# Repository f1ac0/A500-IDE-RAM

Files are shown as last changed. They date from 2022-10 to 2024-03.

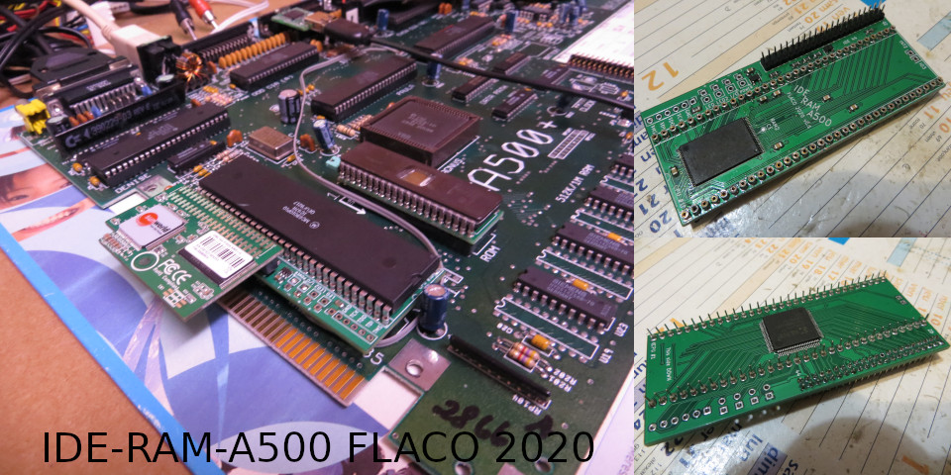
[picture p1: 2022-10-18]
A500-IDE-RAM FLACO 2020.jpg

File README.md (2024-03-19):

# A500-IDE-RAM
This is an expansion for Amiga 500 and plus providing 2MB Fast SRAM and one IDE port. I believe the two things that the A500 lacks the most are probably a hard drive, and Fast RAM.

The RAM is configured by default as 2MB Fast autoconfig (in the 200000-9FFFFF space), and it can be turned into a 1.5MB (fast) RAM in ranger space (C00000-D7FFFF) together with 512KB MapROM. This mode is targeted for owners of plus or expanded rev8a who want to play old picky games from floppies. The modes and maprom can be configured by maintaining the reset from 3 to 10s or by using the provided Amiga software.

Facts about this project :
- It sits under the CPU : does not block access to the ROM and does not need a relocator.
- I wanted a mini-IDE port, this is the main reason why I started to create my own board.
- I thought that it would be neat to have some Fast RAM on the same 2-layers PCB, and I had a great SRAM chip for another project, PCMCIA-SRAM.
- The IDE port simulates the one from the A600 so it is bootable with appropriate Kickstarts. Like other IDE expansions, it requires two additional signals from the motherboard : INT2 and OVR.
- By default, the RAM stuff takes the place of the first expansion in the autoconfig chain. To use other autoconfig expansions, you need to configure the firmware with config_in/out pins to put it in your autoconfig chain ; these pins take the place of the secondary LED.
- Version 0.3 of the board adds a "clockport" to connect compatible expansions. Its "SPARE_CS" is at address D8xxxx. It is untested at the time of writing

# Acknowledgements
Thanks Guys :
- mkl from http://www.mkl211015.altervista.org has created both IDE and RAM expansions, ide68k and ram68k, that sit under the 68000, and can be stacked. I thank him for publishing his schematic and code since it inspired this project, and the base of the IDE CPLD code is a verilog conversion I made from his abel of version 425.
- Sector101 shared an interesting experiment that proved it is somewhat simple to use SRAM as fast memory, and encouraged me to try adding it to this project : https://blog.sector101.co.uk/2019/07/20/amiga-500-2mb-handwired-fastram-expansion/ .
- Sukkopera shared the OpenAmiga500FastRamExpansion from which I used the autoconfig CPLD code in earlier versions : https://github.com/SukkoPera/OpenAmiga500FastRamExpansion/
- the software in this project is inspired by the MapROM tool shared by Paul RASPA (PR77) https://github.com/PR77/A600_ACCEL_RAM/tree/master/Software . This is the first C code I ever compiled for my Amiga, so I believe the MapROM function was achieved thanks to this working starting point !

# Disclaimer
This is a hobbyist project, it comes with no warranty and no support. Also remember that the Amiga machines are about 30 years old and may fail because of such hardware expansions.

I publish my work under the CC-BY-NC-SA license. The content of this repository is the result of weeks of work, requiring investment in tools, parts, prototypes, and risky tests on his own equipment. For this reason the author does not want third parties to sell products and keep all the profit, usually without even offering support to their customers. If you see people selling this without the consent of the author, don't buy from them.

If you find it useful and want to reward my hard work : I am always looking for Amiga/Amstrad CPC hardware to repair and hack, please contact me.

# BOM
- 1x XC95144XL CPLD
- 1x CY62167ELL-45ZXI 5V SRAM (do not use 3.3V CY62167EV !). For 4MB you may also, with small changes in the CPLD code (addressing and autoconfig) :
 - stack a second chip on the first one and connect its pin 12 to the pad nearby -god skills required-,
 - use a CY62177ESL-55ZXI 5V SRAM instead (rare, expensive, not tested).
- 1x 3.3v LDO, either SPX3819M5-L-3-3 or XC6206P332MR
- 2x 1uF (or more) 0805 capacitors
- 5x 100nF 0805 capacitors
- 3x 10k 0805 resistors
- 2x 4k7 0805 resistors
- 1x BAT54A (or equivalent) diodes
- 64x rounded socket pins, for CPU pass-through connection. I use pins taken from a socket header.
- 1x 2x22 2.0mm pin header. Remove pin 20 which is IDE key.
- 2x wires for INT2 and OVR signals
- optional : 1x LED and resistor (330 ohm 0805 for example)

# Making it
Components are SMD, and have thin pin pitch. You need to know what you are doing.

Check for shorts at least between 5V, 3.3V, and GND traces before applying power !

The programming port does not need to be soldered since it needs to be programmed just once : you can just hold it in place during the few seconds required for programming.

CPLD code is generated and built into xsvf using Xilinx ISE 14.7 IDE then iMPACT. There are configuration defines for RAM type and LED/config_pins selection, choose the ones you need. The "Process Properties" of the Fitting step are tweaked :
- -slew = Slow
- -power = Low
- -nogclkopt = Checked (by default)
- -nogsropt = Checked (by default)
- -unused = NOT Checked (by default), since pin 4 is used as pass-through

There are several methods to program the XC95144XL, I personally use xsvfduino. I advise you program it when unplugged from the motherboard, otherwise make sure to power it from the motherboard and not your programmer or it might burn trying to power the whole system.

# Using it
- Remove the 68000 CPU from the motherboard
- Insert the CPU on the expansion. I personally upgraded to a 68010 to gain the quit key ability with WHDLoad
- Plug the expansion in the motherboard. Take care of Pin 1. Push it firmly so it does not pop out of the socket during use, but do not break the CPU socket.
- Connect INT2 and OVR headers to the motherboard
- On the v0.3 board, connect INT6 to use the clockport expansions that need it
- Turn on the Amiga

Maintaining the reset for a few seconds will allow you to :
- 3s : disable MapROM for the next reboot
- 6s : turn off MapROM
- 10s : toggle the ram mode

# Amiga FLACOntrol Software
You may use the provided FLACOntrol software to control the board from your OS. It exists in several flavours, with classic or unix-like command line arguments, or silent with minimal text output.

It provides a MapROM function that writes a 256K or 512K ROM image to F80000-FFFFFF.
It also communicates with this expansion using a control register byte at $00E9Cxxx :
- bit 7 indicates if MapROM is active, write 0 to disable it at next reboot ;
- bit 6 is the current ram mode, 0 for Fast autoconfig and 1 for Ranger MapROM ; write it to change mode at next reboot.

To activate Ranger RAM with MapROM ; this will take effect at next reboot :
```
FLACOntrol -1
```
To map the internal ROM (might speed up the system) :
```
FLACOntrol -i
```
Or a different ROM from file, 256K and 512K are supported :
```
FLACOntrol -f Files:path/kickstart-image-not-swapped-nor-split.rom
```
It will revert to the hardware ROM at next power cycle or with :
```
FLACOntrol -x
```
And revert to the full autoconfig RAM and reboot immediately to take effect :
```
FLACOntrol -0 -r
```

To use the MapROM function more extensively, you may compile the CPLD firmware to provide MapROM by default, then add the following line to your startup-sequence. The -r flag tells the software to reboot the system after the new ROM is loaded, then during next reboot the software will exit since MapROM is already active, and your system will finish to boot with the new ROM :
```
FLACOntrol -f Files:path/kickstart-image-not-swapped-nor-split.rom -r
```

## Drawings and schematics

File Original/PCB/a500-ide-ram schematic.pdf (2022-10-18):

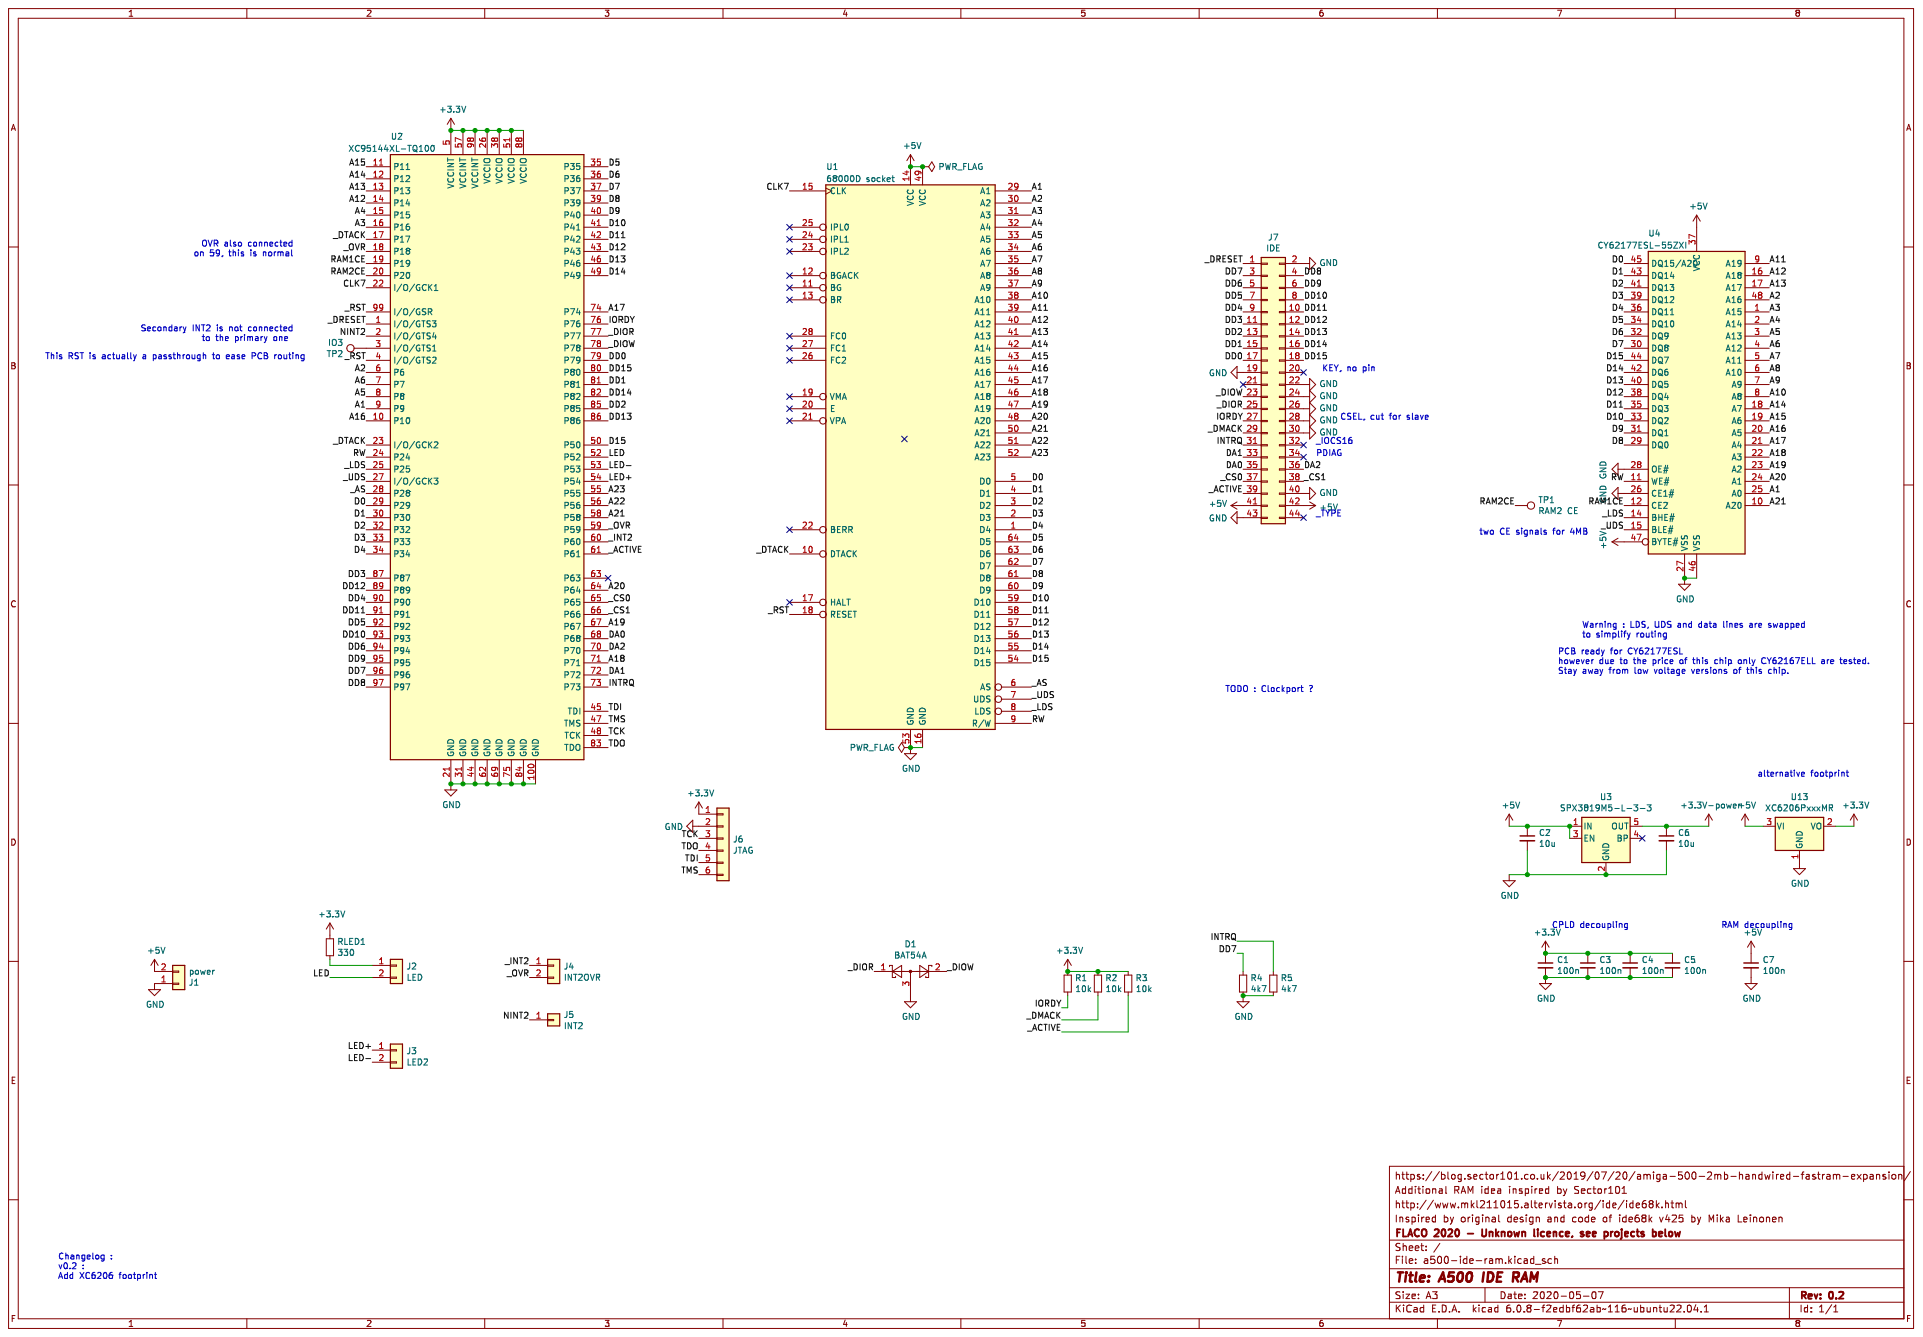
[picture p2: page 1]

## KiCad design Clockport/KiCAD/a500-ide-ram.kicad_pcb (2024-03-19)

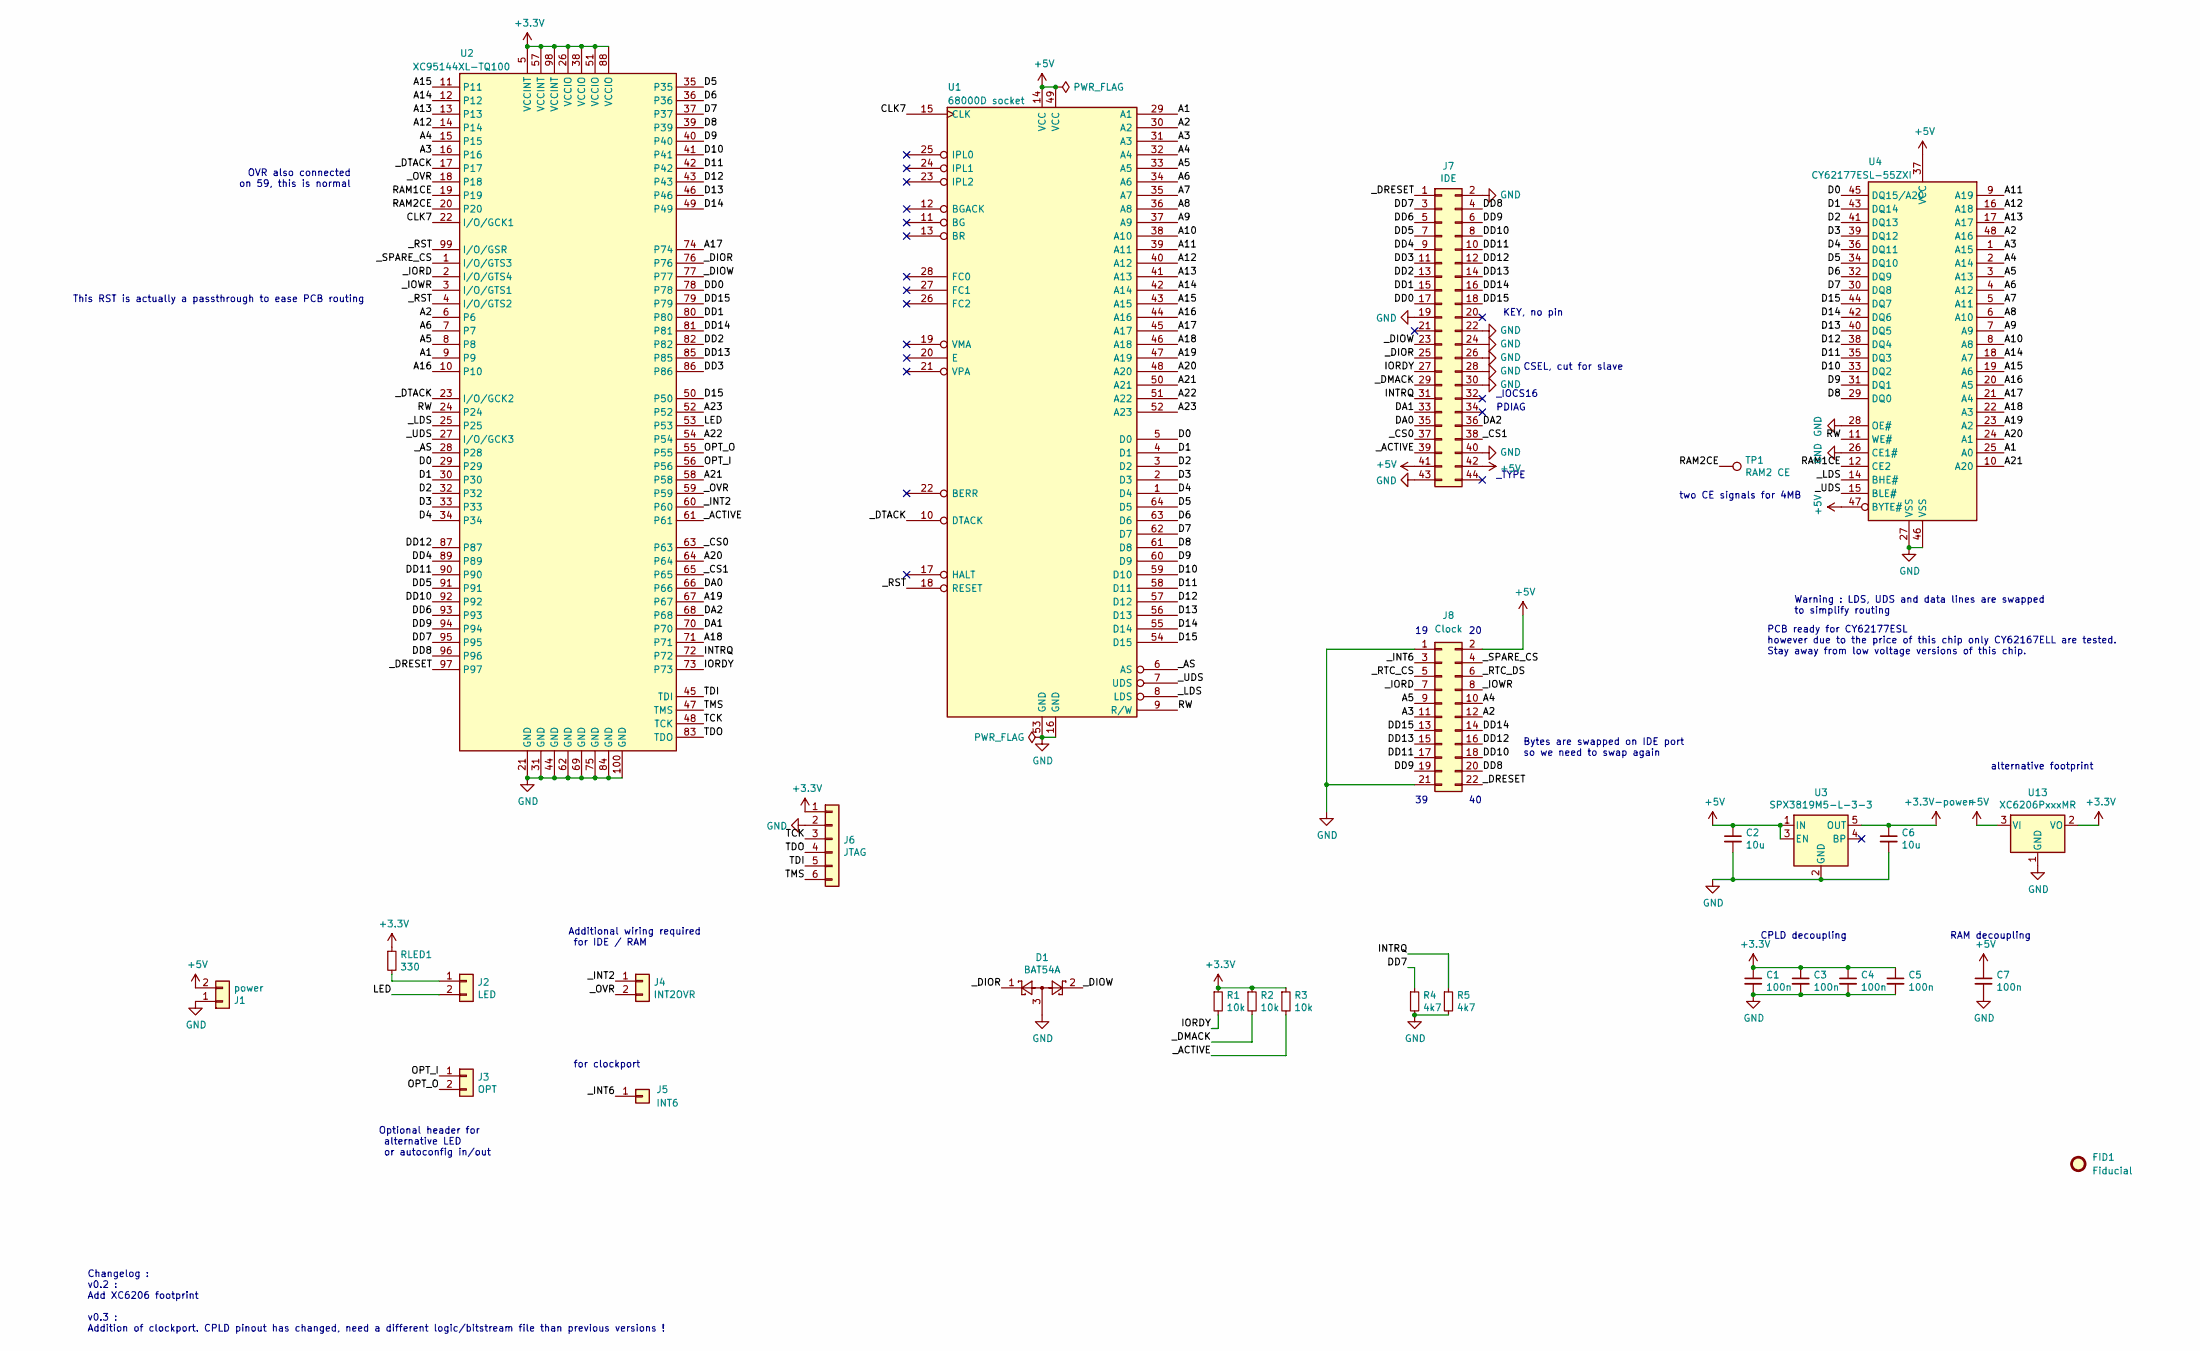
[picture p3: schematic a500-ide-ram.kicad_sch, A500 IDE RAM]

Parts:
C1, C3, C4, C5, C7: 100n; C_0805_2012Metric
C2, C6: 10u; C_0805_2012Metric
D1: BAT54A; SOT-23
FID1: Fiducial; CC_BY_NC_SA_square_silkscreen
J1: power; PinHeader_1x02_P2.54mm_Vertical
J2: LED; PinHeader_1x02_P2.54mm_Vertical
J3: OPT; PinHeader_1x02_P2.54mm_Vertical
J4: INT2OVR; PinHeader_1x02_P2.54mm_Vertical
J5: INT6; PinHeader_1x01_P2.54mm_Vertical
J6: JTAG; PinHeader_1x06_P2.54mm_Vertical
J7: IDE; PinHeader_2x22_P2.00mm_Vertical
J8: Clock; PinHeader_2x11_P2.00mm_Vertical
R1, R2, R3: 10k; R_0805_2012Metric
R4, R5: 4k7; R_0805_2012Metric
RLED1: 330; R_0805_2012Metric
TP1: RAM2 CE; TestPoint_Pad_D1.0mm
U1: 68000D socket; DIP-64_W22.86mm_BigPads1.4
U2: XC95144XL-TQ100; TQFP-100_14x14mm_P0.5mm
U3: SPX3819M5-L-3-3; SOT-23-5
U4: CY62177ESL-55ZXI; TSOP-I-48_18.4x12mm_P0.5mm
U13: XC6206PxxxMR; SOT-23

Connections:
+5V: C2.1, C7.1, J1.2, J7.41, J7.42, J8.2, U1.14 (VCC), U1.49 (VCC), U3.1 (IN), U3.3 (EN), U4.37 (VCC), U4.47 (BYTE#), U13.3 (VI)
/A1: U1.29 (A1), U2.9, U4.25 (A0)
/A2: J8.12, U1.30 (A2), U2.6, U4.48 (A16)
/A3: J8.11, U1.31 (A3), U2.16, U4.1 (A15)
/A4: J8.10, U1.32 (A4), U2.15, U4.2 (A14)
/A5: J8.9, U1.33 (A5), U2.8, U4.3 (A13)
/A6: U1.34 (A6), U2.7, U4.4 (A12)
/A7: U1.35 (A7), U4.5 (A11)
/A8: U1.36 (A8), U4.6 (A10)
/A9: U1.37 (A9), U4.7 (A9)
/A10: U1.38 (A10), U4.8 (A8)
/A11: U1.39 (A11), U4.9 (A19)
/A12: U1.40 (A12), U2.14, U4.16 (A18)
/A13: U1.41 (A13), U2.13, U4.17 (A17)
/A14: U1.42 (A14), U2.12, U4.18 (A7)
/A15: U1.43 (A15), U2.11, U4.19 (A6)
/A16: U1.44 (A16), U2.10, U4.20 (A5)
/A17: U1.45 (A17), U2.74, U4.21 (A4)
/A18: U1.46 (A18), U2.71, U4.22 (A3)
/A19: U1.47 (A19), U2.67, U4.23 (A2)
/A20: U1.48 (A20), U2.64, U4.24 (A1)
/A21: U1.50 (A21), U2.58, U4.10 (A20)
/A22: U1.51 (A22), U2.54
/A23: U1.52 (A23), U2.52
/CLK7: U1.15 (CLK), U2.22 (I/O/GCK1)
/D0: U1.5 (D0), U2.29, U4.45 (DQ15/A20)
/D1: U1.4 (D1), U2.30, U4.43 (DQ14)
/D2: U1.3 (D2), U2.32, U4.41 (DQ13)
/D3: U1.2 (D3), U2.33, U4.39 (DQ12)
/D4: U1.1 (D4), U2.34, U4.36 (DQ11)
/D5: U1.64 (D5), U2.35, U4.34 (DQ10)
/D6: U1.63 (D6), U2.36, U4.32 (DQ9)
/D7: U1.62 (D7), U2.37, U4.30 (DQ8)
/D8: U1.61 (D8), U2.39, U4.29 (DQ0)
/D9: U1.60 (D9), U2.40, U4.31 (DQ1)
/D10: U1.59 (D10), U2.41, U4.33 (DQ2)
/D11: U1.58 (D11), U2.42, U4.35 (DQ3)
/D12: U1.57 (D12), U2.43, U4.38 (DQ4)
/D13: U1.56 (D13), U2.46, U4.40 (DQ5)
/D14: U1.55 (D14), U2.49, U4.42 (DQ6)
/D15: U1.54 (D15), U2.50, U4.44 (DQ7)
/DA0: J7.35, U2.66
/DA1: J7.33, U2.70
/DA2: J7.36, U2.68
/DD0: J7.17, U2.78
/DD1: J7.15, U2.80
/DD2: J7.13, U2.82
/DD3: J7.11, U2.86
/DD4: J7.9, U2.89
/DD5: J7.7, U2.91
/DD6: J7.5, U2.93
/DD7: J7.3, R4.1, U2.95
/DD8: J7.4, J8.20, U2.96
/DD9: J7.6, J8.19, U2.94
/DD10: J7.8, J8.18, U2.92
/DD11: J7.10, J8.17, U2.90
/DD12: J7.12, J8.16, U2.87
/DD13: J7.14, J8.15, U2.85
/DD14: J7.16, J8.14, U2.81
/DD15: J7.18, J8.13, U2.79
/INTRQ: J7.31, R5.1, U2.72
/IORDY: J7.27, R1.2, U2.73
/LED: J2.2, U2.53
/OPT_I: J3.1, U2.56
/OPT_O: J3.2, U2.55
/RAM1CE: U2.19, U4.12 (CE2)
/RAM2CE: TP1.1, U2.20
/RW: U1.9 (R/W), U2.24, U4.11 (WE#)
/TCK: J6.3, U2.48 (TCK)
/TDI: J6.5, U2.45 (TDI)
/TDO: J6.4, U2.83 (TDO)
/TMS: J6.6, U2.47 (TMS)
/_ACTIVE: J7.39, R3.2, U2.61
/_AS: U1.6 (AS), U2.28
/_CS0: J7.37, U2.63
/_CS1: J7.38, U2.65
/_DIOR: D1.1, J7.25, U2.76
/_DIOW: D1.2, J7.23, U2.77
/_DMACK: J7.29, R2.2
/_DRESET: J7.1, J8.22, U2.97
/_DTACK: U1.10 (DTACK), U2.17, U2.23 (I/O/GCK2)
/_INT2: J4.1, U2.60
/_INT6: J5.1, J8.3
/_IORD: J8.7, U2.2 (I/O/GTS4)
/_IOWR: J8.8, U2.3 (I/O/GTS1)
/_LDS: U1.8 (LDS), U2.25, U4.14 (BHE#)
/_OVR: J4.2, U2.18, U2.59
/_RST: U1.18 (RESET), U2.4 (I/O/GTS2), U2.99 (I/O/GSR)
/_RTC_CS: J8.5
/_RTC_DS: J8.6
/_SPARE_CS: J8.4, U2.1 (I/O/GTS3)
/_UDS: U1.7 (UDS), U2.27 (I/O/GCK3), U4.15 (BLE#)
GND: C1.2, C2.2, C3.2, C4.2, C5.2, C6.2, C7.2, D1.3, J1.1, J6.2, J7.2, J7.19, J7.22, J7.24, J7.26, J7.28, J7.30, J7.40, J7.43, J8.1, J8.21, R4.2, R5.2, U1.16 (GND), U1.53 (GND), U2.21 (GND), U2.31 (GND), U2.44 (GND), U2.62 (GND), U2.69 (GND), U2.75 (GND), U2.84 (GND), U2.100 (GND), U3.2 (GND), U4.26 (CE1#), U4.27 (VSS), U4.28 (OE#), U4.46 (VSS), U13.1 (GND)
unnamed: J2.1, RLED1.2

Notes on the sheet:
PDIAG
alternative footprint
Bytes are swapped on IDE port so we need to swap again
CPLD decoupling
two CE signals for 4MB
for clockport
CSEL, cut for slave
This RST is actually a passthrough to ease PCB routing
_TYPE
Optional header for alternative LED or autoconfig in/out
KEY, no pin
Warning : LDS, UDS and data lines are swapped to simplify routing
Additional wiring required for IDE / RAM
RAM decoupling
Changelog : v0.2 : Add XC6206 footprint v0.3 : Addition of clockport. CPLD pinout has changed, need a different logic/bitstream file than previous versions !
OVR also connected on 59, this is normal
PCB ready for CY62177ESL however due to the price of this chip only CY62167ELL are tested. Stay away from low voltage versions of this chip.
_IOCS16

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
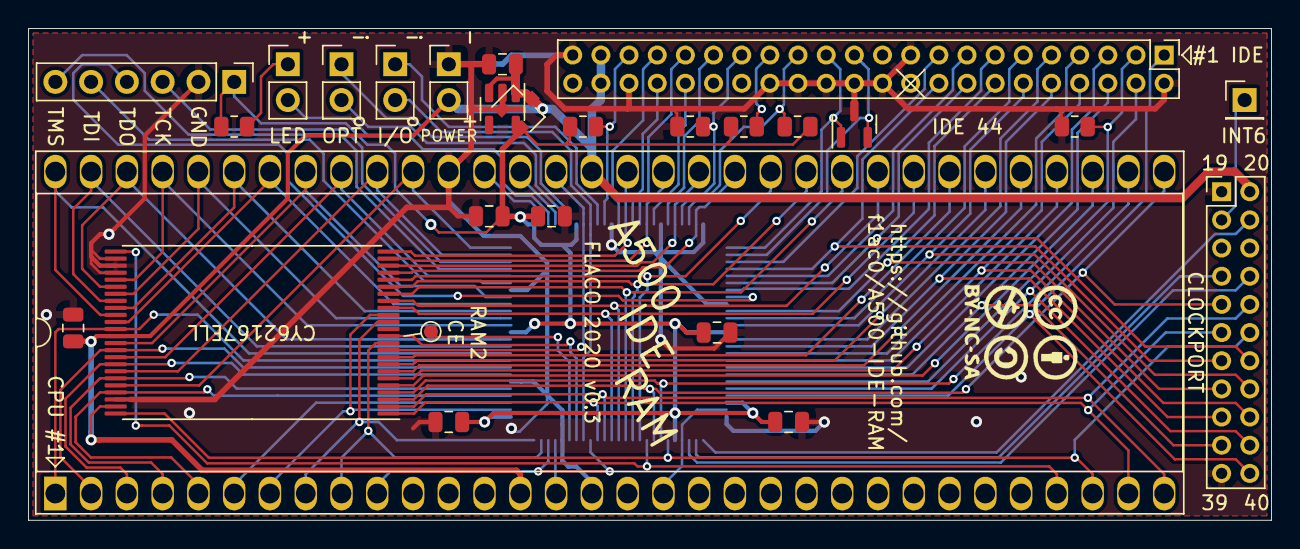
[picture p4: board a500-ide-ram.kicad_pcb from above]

Board: 2 copper layers, 88.3 x 34.9 mm, 29 parts (1 on the bottom side), 93 nets.

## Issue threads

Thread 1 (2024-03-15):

troubles

volton-svg, 2024-03-15:
Hello! I assembled this device and I have a problem - it doesn’t work!
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
Only Fpga is installed without memory chips, then the network is just an ide controller. Should it work without memory chips??? Instead of bat54a, I installed two low-voltage diodes; can such a replacement affect anything? Could you please add the source code for this controller to GitHub?

volton-svg, 2024-03-15:
int2 & ovr are wired correctly, they are simply not visible. When you turn on the machine, it thinks and this screen pops up. The LED does not blink. Memory cards work fine on another machine (ffs, 3.1). fpga has been tested for soldering - everything is ok.motherboard a500+ rev8a ks3.1

f1ac0, 2024-03-15:
Hi.
With the default "combo ram" CPLD logic, then the ram chip is required when in fast autoconfig ram mode, since the system will try to use the 2MB of RAM that is announced by the autoconfig mechanism.
In "ranger/maprom" mode, after a long reset, it should work since the RAM is probed by the kickstart and it will just detect nothing.
I will add the source code to the repo, and mabe a "no ram" binary.

About the IDE port, make sure it is connected to the right pins on your CF adapter, since I designed it to use a pin header and a ribbon cable over the top of the board, not below.
With hand-soldered QFPs, I often get a loose pin here and there, so you may check that they are all OK. Usually with a strong led light under the 2-layer PCB it is also easy to check that there are no solder bridges between pins.
About the diodes, just make sure they are the right way around.

volton-svg, 2024-03-15:
When the reset is held for a long time (about 15 seconds), the Amiga goes to the usual screen with a floppy disk. The hard drive activity LED is not lit or blinking. When the jumper is removed from the master slave adapter and the adapter is switched to slave mode, the activity LED starts to light constantly.

volton-svg, 2024-03-15:
in slave mode, when turned on, the readiness LED is constantly on and the Amiga thinks... long reset (15 sec) the LED does not light up, the Amiga thinks anyway, as if it is looking for a device but does not find it... when resetting, the LED does not react in any way, the Amiga thinks and goes to the floppy disk ... after resetting and clicking two mouse buttons into the boot menu, nothing else was found except the drive.

f1ac0, 2024-03-15:
When in "ranger/maprom" mode, no autoconfig information is reported to the system, so no extension board is listed in the boot menu, I understand that what you get is normal on this side.
The drive should work in master mode.
I checked that INT2 and OVR are routed to both the I/O header and the one at the bottom of the CPU. (I don't see solder on the I/O header on your photo so I assume you connected the latter one, this should be fine).
I assembled two board that are working in my REV8a.1 system with DOMs and SD to IDE adapters (or "were working" before I recently zapped my Agnus with ESD while playing with a dodgy ZIF64 socket...). So far I never tried CF adapters but I believe it should work if your CF are working in IDE mode with other systems.

Please check that the IDE port is wired correctly to the CF adapter, as I wrote in the previous comment.

volton-svg, 2024-03-15:
I think everything is soldered correctly! since ide 44 has a key hole (20 pin) which is always free (key no pin) and I also did not solder this pin hole on the adapter completely coincides with the hole on the board... so everything will be correct.

volton-svg, 2024-03-18:
Today I rechecked all connections fpga <->ide, fpga <->cpu, everything is working. power is coming to the fpga, there are no short circuits... hmm, I can only think about the firmware... :(

f1ac0, 2024-03-19:
All source files are now in the repo. I checked that no change was made to this "original version" since I built my own working boards.

f1ac0, 2024-04-09:
Hi,
Did you find a solution to your problem ?

I looked at a commercial CF to mini IDE adapter. If yours came with male pin headers for the IDE connector, and you just soldered that below tour A500-IDE-RAM board, then I believe that the odd and even pins are swapped (or maybe worse the connector may be 180° around, mixing power and data lines). These CF to mini IDE adapters with male pin headers are designed to be connected to the host using a ribbon cable.

To install a commercial adapter like you did, then it must come with a female pin socket (designed to be plugged directly on a host motherboard without ribbon cable, I am not sure if it even exists), then you must remove that socket and solder a pin header on the other side of the PCB, and then the pins could match with the A500-IDE-RAM board when plugged from below. If it is not commercially available, then it should be fairly straightforward to design such a custom board.

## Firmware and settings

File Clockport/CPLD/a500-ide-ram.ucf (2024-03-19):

# A500-IDE-RAM-CLOCKPORT

NET _AS LOC=P28;
NET R_W LOC=P24;
NET _UDS LOC=P27;
NET _LDS LOC=P25;
NET _DTACK LOC=P23;
NET _DTACK2 LOC=P17;
NET _OVR PWR_MODE=STD;
NET _OVR FAST;
NET _OVR LOC=P59;
NET _OVR2 PWR_MODE=STD;
NET _OVR2 FAST;
NET _OVR2 LOC=P18;
NET _INT2 LOC=P60;
NET _RESET LOC=P99;
NET CLK LOC=P22;
NET AH<23> LOC=P52;
NET AH<22> LOC=P54;
NET AH<21> LOC=P58;
NET AH<20> LOC=P64;
NET AH<19> LOC=P67;
NET AH<18> LOC=P71;
NET AH<17> LOC=P74;
NET AH<16> LOC=P10;
NET AH<15> LOC=P11;
NET AH<14> LOC=P12;
NET AH<13> LOC=P13;
NET AH<12> LOC=P14;
NET AL<6> LOC=P7;
NET AL<5> LOC=P8;
NET AL<4> LOC=P15;
NET AL<3> LOC=P16;
NET AL<2> LOC=P6;
NET AL<1> LOC=P9;
NET D<15> LOC=P50;
NET D<14> LOC=P49;
NET D<13> LOC=P46;
NET D<12> LOC=P43;
NET D<11> LOC=P42;
NET D<10> LOC=P41;
NET D<9> LOC=P40;
NET D<8> LOC=P39;
NET D<7> LOC=P37;
NET D<6> LOC=P36;
NET D<5> LOC=P35;
NET D<4> LOC=P34;
NET D<3> LOC=P33;
NET D<2> LOC=P32;
NET D<1> LOC=P30;
NET D<0> LOC=P29;

//NET IORDY LOC=P73;
NET INTRQ LOC=P72;
NET _ACTIVE LOC=P61;
NET DD[7] LOC=P95;
NET DD[6] LOC=P93;
NET DD[5] LOC=P91;
NET DD[4] LOC=P89;
NET DD[3] LOC=P86;
NET DD[2] LOC=P82;
NET DD[1] LOC=P80;
NET DD[0] LOC=P78;
NET DD[15] LOC=P79;
NET DD[14] LOC=P81;
NET DD[13] LOC=P85;
NET DD[12] LOC=P87;
NET DD[11] LOC=P90;
NET DD[10] LOC=P92;
NET DD[9] LOC=P94;
NET DD[8] LOC=P96;
NET _DRESET LOC=P97;
NET DA<2> LOC=P68;
NET DA<1> LOC=P70;
NET DA<0> LOC=P66;
NET _CS[1] LOC=P65;
NET _CS[0] LOC=P63;
NET _DIOW LOC=P77;
NET _DIOR LOC=P76;

NET _LED LOC=P53;
NET OPTPIN_O LOC=P55;
NET OPTPIN_I LOC=P56;
NET RAM1CE LOC=P19;
NET RAM2CE LOC=P20;

NET _IORD LOC=P2;
NET _IOWR LOC=P3;
NET _SPARE_CS LOC=P1;

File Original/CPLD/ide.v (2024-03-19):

// Inspired by original design and code of ide68k v425 by Mika Leinonen
// now offline :http://www.mkl211015.altervista.org/ide/ide68k.html
// https://web.archive.org/web/20200221025111/http://www.mkl211015.altervista.org/ide/ide68k.html
//
// Schematic and PCB converted and merged in KiCAD, code converted to Verilog, merged, adapted, and everything tested by FLACO 2020
// This file Created 25-Apr-2020 10:08 AM
//
// ide68k license is unknown
// 

module ide(
//68000 bus
	input _AS,
	input R_W,
	input _UDS,
	input _LDS,
	input _RESET,
	input CLK,
	input [23:12] AH,
	input [4:2] AL, //6,5,1 added for RAM
	input [15:0] DIN,
	output [15:0] DOUT,
	output D8_OE,
	output D0_OE,
	output IDERANGE,
	output _INT2,

//IDE
//	input IORDY,
	input INTRQ,
	input _ACTIVE,
	input [15:0] DDIN,
	output [15:0] DDOUT,
	output DD8_OE,
	output DD0_OE,
	output reg _DRESET,
	output reg [2:0] DA,
	output reg [1:0] _CS,
	output _DIOW,
	output _DIOR,

//LEDs
	output _LED,
	output reg Xled_OE,
	output reg Xled_ZD,
	output reg Xledpos
	);

	wire [7:0] dl_ZD;
	reg [15:8] dh_ZD;
	assign DOUT[15:0] = {dh_ZD[15:8], dl_ZD[7:0]};
	
	reg [2:0] snr;
	reg [2:0] stidreg;
	reg [2:0] stidreg_D;
   reg n_reset_clocked, daspi, dasp_s,
	 ledst1_D, ledst0_D, bit_from_sm,
	 not_nas_at_last_clk_rise, irq_synch0,
	 forceasif_ideintrq_DA8000, irq_synch1, lastbitda8000,
	 int2_DA9000, int2generationenable_DAA000,
	 int2generationenable_DAA000_D, int2_DA9000_D,
	 forceasif_ideintrq_DA8000_D, ledst0, ledst1,
	 n_reset_clocked_D;

   // initial {snr[0], snr[1], snr[2], n_reset_clocked, daspi,
   //       dasp_s, not_nas_at_last_clk_rise, irq_synch0,
   //       forceasif_ideintrq_DA8000, irq_synch1, lastbitda8000,
   //       int2_DA9000, int2generationenable_DAA000, stidreg[0],
   //       stidreg[1], stidreg[2], ledst0, ledst1, _CS[0], _CS[1],
   //       DA[0], DA[1], DA[2], _DRESET} = 24'h0;

//clocked signals
	always @(posedge CLK) begin
		snr[0] <= _RESET;
		snr[1] <= snr[0];
		snr[2] <= snr[1];
      n_reset_clocked <= n_reset_clocked_D;
	end

	always @(posedge CLK or negedge n_reset_clocked)
		if (!n_reset_clocked) begin
			daspi <= 1'h0;
			dasp_s <= 1'h0;
			_DRESET <= 1'h0;
			{ledst1, ledst0} <= 2'h0;
			irq_synch0 <= 1'h0;
			irq_synch1 <= 1'h0;
			not_nas_at_last_clk_rise <= 1'h0;
		end else begin
			daspi <= !_ACTIVE;
			dasp_s <= daspi;
			_DRESET <= 1'b1;
			{ledst1, ledst0} <= {ledst1_D, ledst0_D};
			irq_synch0 <= INTRQ;
			irq_synch1 <= irq_synch0;
			not_nas_at_last_clk_rise <= !_AS;
		end

	always @(negedge _AS or negedge n_reset_clocked)
		if (!n_reset_clocked) begin
			DA[2] <= 1'h1;
			DA[1] <= 1'h1;
			DA[0] <= 1'h1;
			_CS[1] <= 1'h1;
			_CS[0] <= 1'h1;
		end else begin
			DA[2] <= AL[4];
			DA[1] <= AL[3];
			DA[0] <= AL[2];
			_CS[1] <= ! (AH[23:12] == 12'b1101_1010_0001 | AH[23:12] == 12'b1101_1010_0011);
			_CS[0] <= ! (AH[23:12] == 12'b1101_1010_0000 | AH[23:12] == 12'b1101_1010_0010);
		end
 
	always @(posedge _AS or negedge n_reset_clocked)
		if (!n_reset_clocked) begin
			forceasif_ideintrq_DA8000 <= 1'h0;
			lastbitda8000 <= 1'h0;
			int2_DA9000 <= 1'h0;
			int2generationenable_DAA000 <= 1'h0;
			stidreg[2:0] <= 3'h0;
		end else begin
			forceasif_ideintrq_DA8000 <= forceasif_ideintrq_DA8000_D;
			lastbitda8000 <= irq_synch1 | forceasif_ideintrq_DA8000;
			int2_DA9000 <= int2_DA9000_D;
			int2generationenable_DAA000 <= int2generationenable_DAA000_D;
			stidreg[2:0] <= stidreg_D[2:0];
		end


// Start of original equations

//reset line filter
   always @(snr[1] or snr[2] or n_reset_clocked) begin
      n_reset_clocked_D = 1'b0;
      if (snr[1] == snr[2]) begin
	 n_reset_clocked_D = snr[2];
      end else begin
	 n_reset_clocked_D = n_reset_clocked;
      end
   end
	
//leds and misc
//Secondary led outputs need external series resistor
   assign _LED = !dasp_s;
   always @(ledst0 or ledst1 or dasp_s) begin
      {Xled_ZD, Xledpos, Xled_OE, ledst1_D, ledst0_D} = 5'b0_0000;
      case ({ledst1, ledst0})
      2'b00: begin
	    Xled_ZD = 1'b0;
	    Xledpos = 1'b1;
	    Xled_OE = 1'b1;
	    if (dasp_s) begin
	       {ledst1_D, ledst0_D} = 2'b00;
	    end else begin
	       {ledst1_D, ledst0_D} = 2'b01;
	    end
	 end
      2'b01: begin
	    Xled_ZD = 1'b1;
	    Xledpos = 1'b1;
	    Xled_OE = 1'b1;
	    {ledst1_D, ledst0_D} = 2'b10;
	 end
      2'b10: begin
	    Xled_ZD = 1'b1;
	    Xledpos = 1'b1;
	    Xled_OE = 1'b0;
	    {ledst1_D, ledst0_D} = 2'b11;
	 end
      2'b11: begin
	    Xled_ZD = 1'b1;
	    Xledpos = 1'b0;
	    Xled_OE = 1'b0;
	    if (dasp_s) begin
	       {ledst1_D, ledst0_D} = 2'b00;
	    end else begin
	       {ledst1_D, ledst0_D} = 2'b11;
	    end
	 end
      endcase
   end
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

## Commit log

2020-08-28 Respository init with v0.1 KiCAD files, CPLD source, Readme and License
    [ide-ram-a500.kicad_pcb, ide-ram-a500.sch]
2021-02-13 Updated CPLD code with new autoconfig, new ranger-maprom, rewritten IDE ; new MapROM software ; 0.2 hardware
    [ide-ram-a500.kicad_pcb, ide-ram-a500.sch]
2022-10-18 Change project name to match other projects. Kicad: conversion to Kicad 6, repo URL on PCB silkscreen.
    [a500-ide-ram.kicad_pcb, a500-ide-ram.kicad_sch, ide-ram-a500.kicad_pcb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]
2022-10-18 Public repository init with schematic, Gerbers, ibom, CPLD xsvf, Software, Photo, Readme, License
    [a500-ide-ram-B_Cu.gbl, a500-ide-ram-B_Mask.gbs, a500-ide-ram-B_Paste.gbp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]
2022-10-22 KiCAD : correct license on schematic and PCB
    [a500-ide-ram.kicad_pcb, a500-ide-ram.kicad_sch]
2023-06-14 Addition of v0.3 with clockport KiCAD and CPLD files. v0.2 has been moved to the "Original" subdirectory.
    [a500-ide-ram.kicad_pcb, a500-ide-ram.kicad_sch]

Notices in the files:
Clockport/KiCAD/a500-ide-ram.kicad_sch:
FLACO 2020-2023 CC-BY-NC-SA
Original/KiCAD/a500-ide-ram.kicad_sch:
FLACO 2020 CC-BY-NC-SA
